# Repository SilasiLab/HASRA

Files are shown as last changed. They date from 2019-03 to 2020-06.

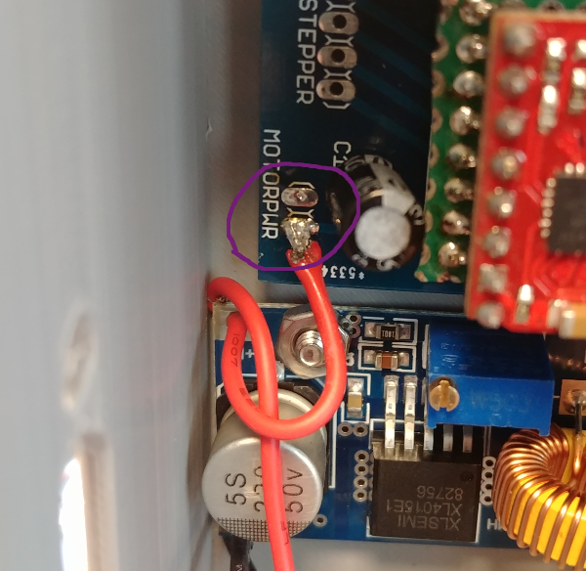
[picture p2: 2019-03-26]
resources/Images/STEP12.png

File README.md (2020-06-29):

# **Overview**:

This system allows the user to host up to 5 mice in their home environment and automatically administer the single pellet reaching test to those animals. The system can run unsupervised and continuously for weeks at a time, allowing all 5 mice to perform an unlimited number of single pellet trials at their leisure. 

The design allows a single mouse at a time to enter the reaching tube. Upon entry, the animal’s RFID tag will be read, and if authenticated, a session will start for that animal. A session is defined as everything that happens from the time an animal enters the reaching tube to when they leave the tube. At the start of a session, the animal’s profile will be read and the task difficulty as well as the left and right preference will be automatically adjusted by moving the pellet presentation arm to the appropriate distance both away from the reaching tube and from right to left. Pellets will continue to be presented periodically until the mouse leaves the tube, at which point the session will end. Video and other data is recorded for the duration of each session. At session end, all the data for the session is saved in an organized way. We also have an auxiliary function for counting the successful rate of displaying a pellet using MobileNetV2 based on tensorflow and keras.

For further analyse, you can check the repository posted here:
https://github.com/SilasiLab/HomecageSinglePellet_Manual

# **Dependencies:**
* Ubuntu v16.04 LTS: Kernel version 4.4.19-35 or later
* Or Windows 10 is recommended, since the backend camera driver performs better that the one on linux in our experiment.
* Anaconda 3 environment, for the dependancies without a version number, it means there is no specific requirement on it. 
	* Python==3.6.10
	* pySerial==3.4	
	* numpy==1.18.1
	* OpenCV=4.1.2 (A whl file is provided under requirment folder.)
	* tkinter=8.6.8
	* matplotlib=3.1.3
	* Pillow
	* tqdm
	* tensorflow=1.10.0
	* keras=2.2.4
	* psutil
	* multiprocessing
	* subprocess
	
* Arduino IDE v1.8.5

# **Software Installation:**
1. Windows 10 is strongly recommended for a better support of camera driver. Ubuntu 16.04 LTS is alternative.
2. Install Anaconda. (https://www.anaconda.com/distribution/)
3. Install Arduino IDE v1.8.5. (https://www.arduino.cc/en/Main/Software)
	
4. Create and configure a virtual environment for installing the HomeCageSinglePellet code.
	- `conda create -n <yourenvname> python=3.6.10 anaconda`
	- `conda activate <yourenvname>`
	- `conda install -c anaconda numpy==1.18.1`
	- `conda install -c anaconda pyserial==3.4`
	- `conda install -c anaconda tk==8.6.8`
	- `conda install -c conda-forge matplotlib`
	- `conda install tqdm`
	- `conda install Pillow`
	- `conda install tensorflow==1.10.0`
	- `conda install keras==2.2.4`
	- `pip install psutil`

5. `git clone https://github.com/SilasiLab/HomeCageSinglePellet_server.git`
6. `pip install /path/to/HASRA/dependencies/opencv_python-4.1.2+contrib-cp36-cp36m-win_amd64.whl`
7. Add ID of cage to the name of folder as postfix. (Rname the folder of the downloaded reporsitory as HASRA_[id]).
8. Create folders and profiles of the animals by running the  `genProfiles.py `
	- `conda activate [name of your environment]`
	- `cd /path/to/HASRA/src/client`
	- `python genProfiles.py`
# **Assembly:**

The detailed assembly manual can be found here:
https://github.com/SilasiLab/HomeCageSinglePellet_server/blob/master/Homecage%20assembly%20manual.pdf

# **Usage**:
### **Running the Device**
1. Enter the virtual environment that the system was installed in by typing `conda activate <my_env>` into a terminal.

2. Optional: Use `cd` to navigate to` HomeCageSinglePellet_server/src/client/` and then run `python -B genProfiles.py`. The text prompts will walk you through entering your new animals into the system. Since the folder and the file are already inclued in this repo, this step is optional.

3. Open HomeCageSinglePellet_server/config/config.txt and set the system configuration you want.

4. Find the COM port ids for Arduino and RFID reader, using `mode` command in terminal.
(In linux: Arduino needs to be USB0 , and RFID reader needs to be USB1. You can see connected USB devices with terminal command:
ls /dev/tty* and You need to replace the COMs in main.py -> `sys_init()` function manually.) 
  
5. Open a termanal and run following command:
* `cd \your\path\to\HomeCageSinglePellet_server\src\client\`
* `conda activate YourEnvironment` replace YourEnvironment by the name of your environment.
* `python main.py COM-arduino COM-RFID` replace COM-arduino and COM-RFID by the COM ids of Arduino and RFID respectively.

6. Optional: If you have a google file stream mounted on this computer, you can choose to upload all the viedos and log files to google drive. You need firstly find out the local path to this google drive folder, in this case it is: `G:\Shared drives\SilasiLabGdrive`.
Since there could be mutiple cage running on the same computer and they can also be stored in the same google cloud folder. You can add a suffix to the project foler name by changing the root folder name from `HomeCageSinglePellet_server` to `HomeCageSinglePellet_server_id`(replace the id by your id) 
In the same folder, open another terminal and activate the virtual environment again, then run `python googleDriveManager.py \path\to\your\cloud\drive\folder`.
The videos and the log files will be stored in `your cloud drive\homecage_id_sync`.

7. You need to put in the RFID tag numbers manually into the profiles. Take mouse 1 as an instance, you need to replace the first line in `HomeCageSinglePellet_server\AnimalProfiles\MOUSE1\MOUSE1_save.txt`. If you do not know your tag number, don't worry. You can scan it on the RFID reader, it will be printed in the Terminal as `[tag number] not recognized`.

8. To test that everything is running correctly, block the IR beam breaker with something
	and scan one of the system’s test tags. If a session starts properly, it’s working. You will also be able to find out hom many pellets have been succefully displayed out of current displays we have as it is shown in the terminal too. 

9. To shut the system down cleanly; 

	- Ensure no sessions are currently running. 
	- Press the quit button on the GUI.
	- Ctrl+c out of the program running in the terminal.

# **Troubleshooting**:

* Is everything plugged in?
* Make sure you are in the correct virtual environment.
* Make sure the HomeCageSinglePellet/config/config.txt file contains the correct configuration. (If the file gets deleted it will be replaced by a default version at system start)
* Make sure there are 1 to 5 profiles in the HomeCageSinglePellet/AnimalProfiles/ directory. Ensure these profiles contain all the appropriate files and that the save.txt file for each animal contains the correct information.

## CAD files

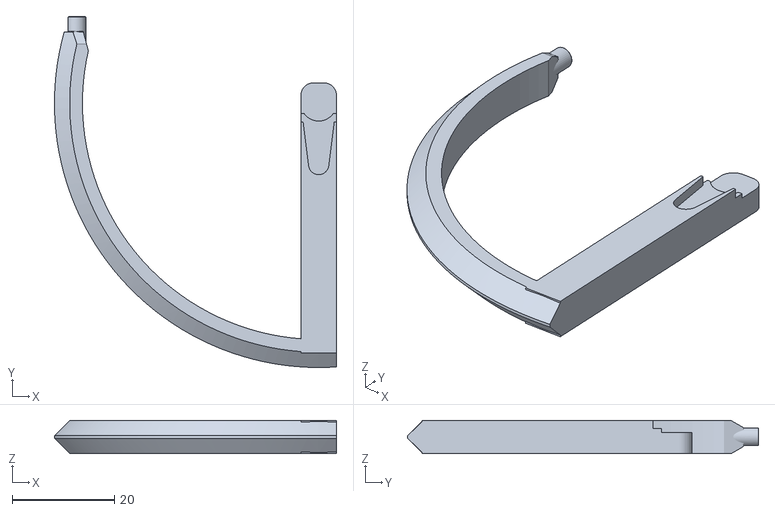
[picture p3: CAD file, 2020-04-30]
CAD/Arm.STL
55.3 x 68.8 x 6.50

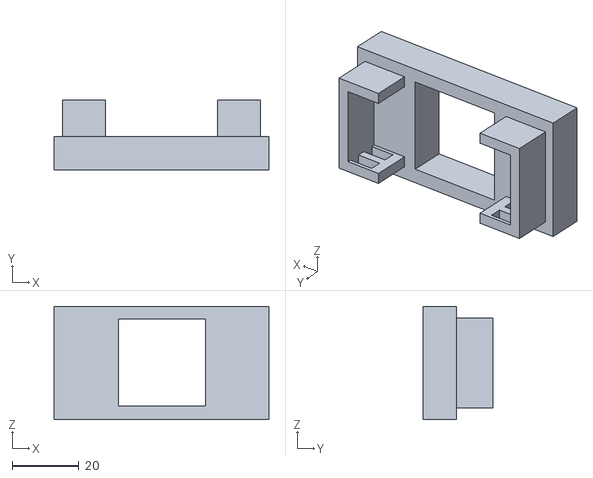
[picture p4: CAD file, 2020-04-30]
CAD/Beam_Breaker_Mount.STL
64.5 x 21.1 x 34.0

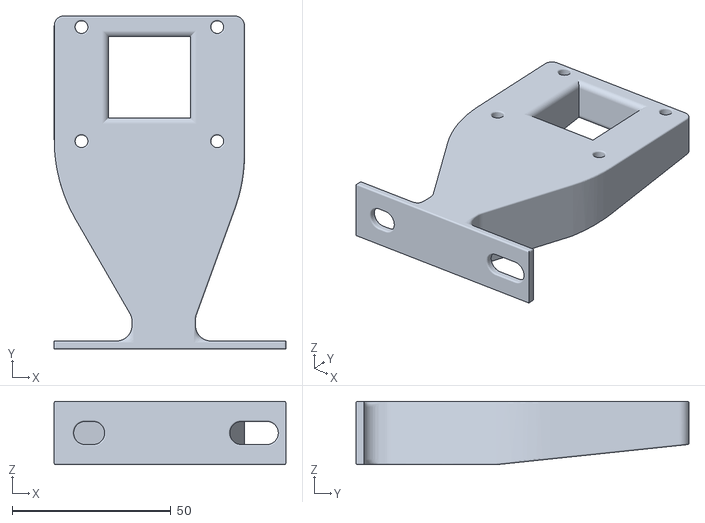
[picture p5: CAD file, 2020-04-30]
CAD/Standard.STL
73.0 x 105.0 x 20.0

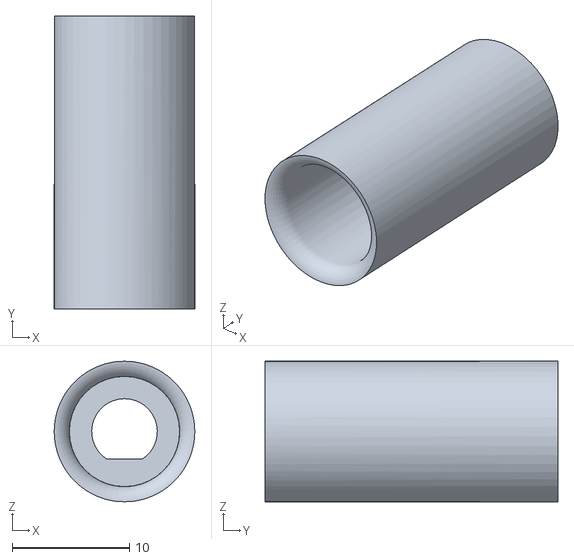
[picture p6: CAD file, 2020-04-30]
CAD/Motor_coupler.STL
12.0 x 25.0 x 12.0

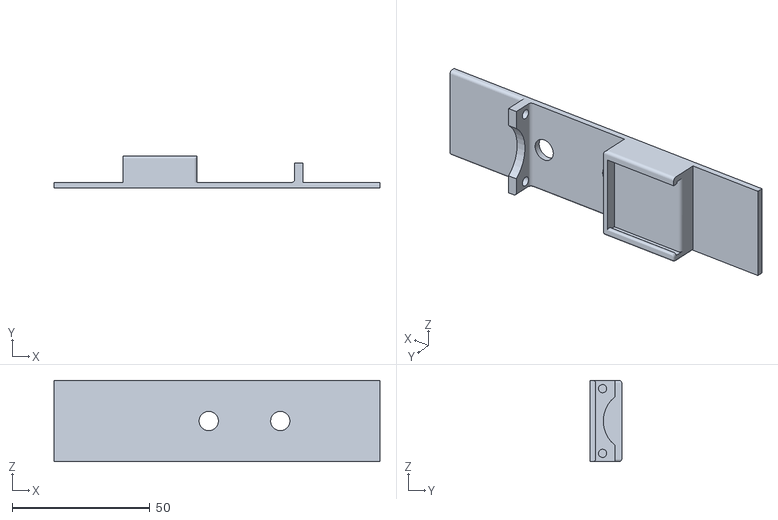
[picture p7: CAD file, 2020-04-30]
CAD/Moving_Stage_Bottom.STL
118.5 x 11.5 x 29.5

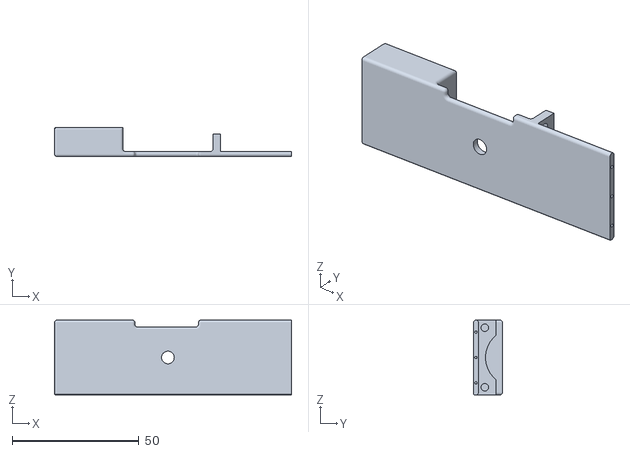
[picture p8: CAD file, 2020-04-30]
CAD/Moving_Stage_Top.STL
93.5 x 11.5 x 29.5

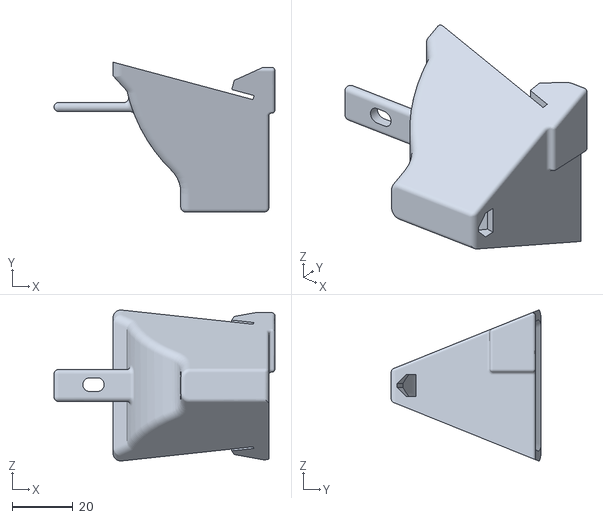
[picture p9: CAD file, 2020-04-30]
CAD/Hopper.STL
72.7 x 49.3 x 49.7

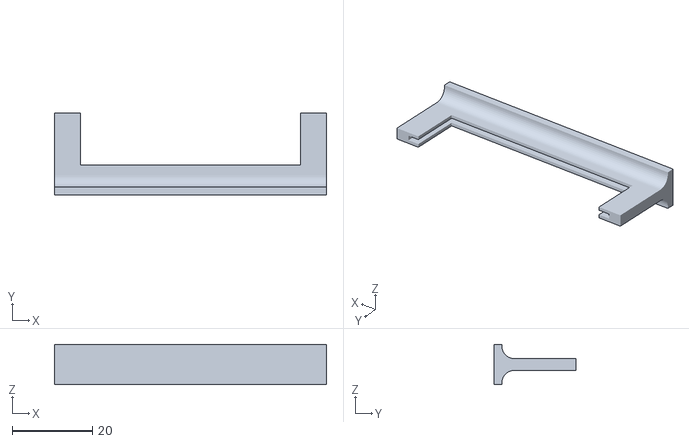
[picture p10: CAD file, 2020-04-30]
CAD/Light_Holder.STL
68.0 x 20.5 x 10.0

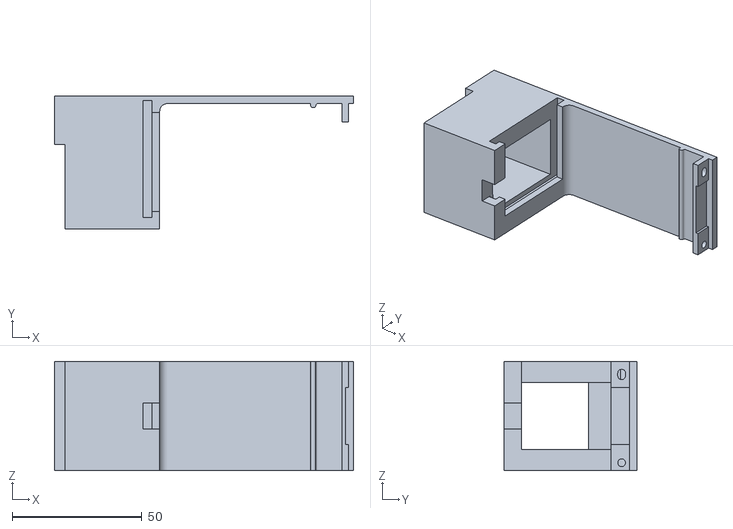
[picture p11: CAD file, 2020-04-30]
CAD/Tubeholder_3cm.STL
115.1 x 51.4 x 42.0

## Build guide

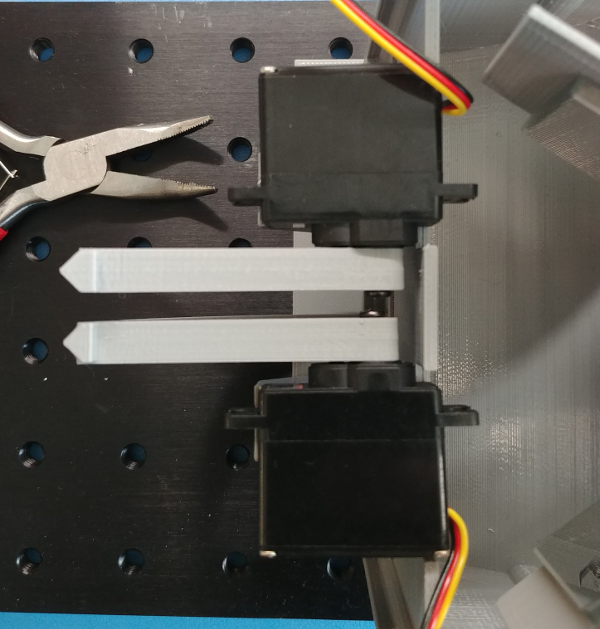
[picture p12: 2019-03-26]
resources/Images/STEP31.png

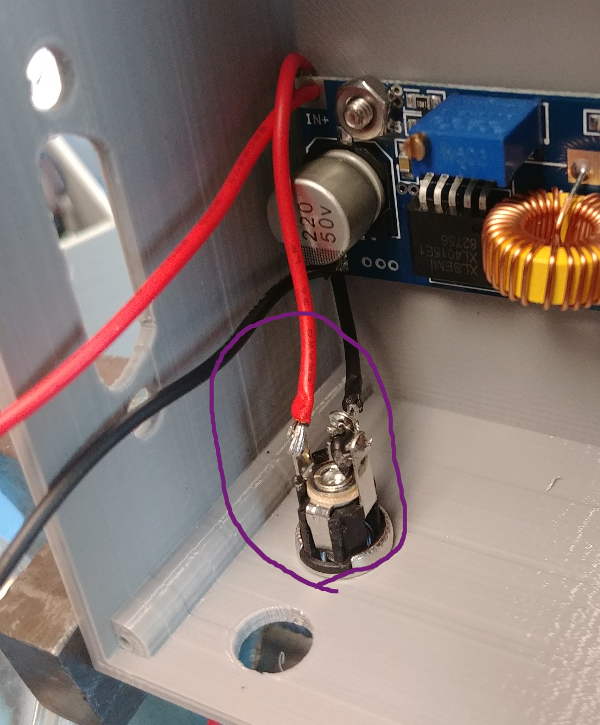
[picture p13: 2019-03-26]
resources/Images/STEP10.png

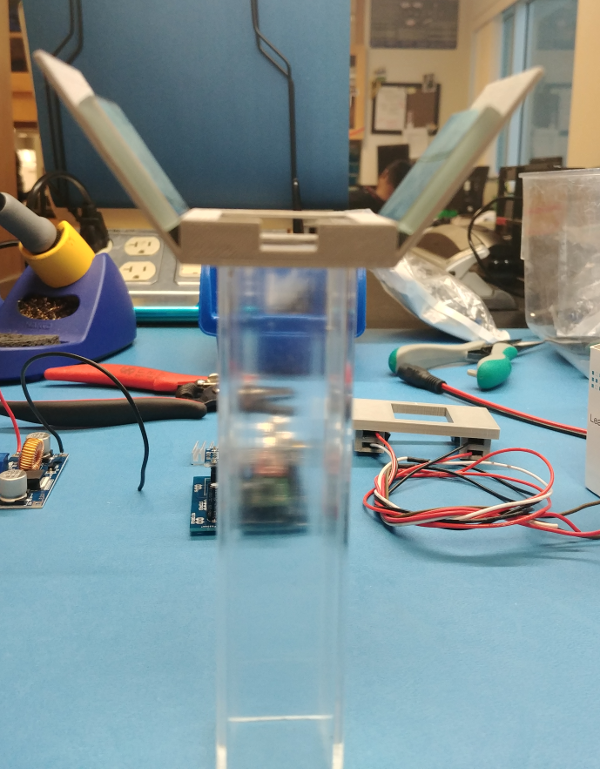
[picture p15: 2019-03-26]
resources/Images/STEP22.png

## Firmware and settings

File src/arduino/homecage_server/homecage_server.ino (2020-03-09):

/*
    This program is a server for controlling the hardware peripherals attached to the HomeCage system.
    It waits for commands over a serial port (python client in our case) and performs the desired action upon receiving the command.
    There is no proper message passing system and it simply uses various magic byte values as messages.
    Note: These bytes can cause different outcomes depending on the state the program is in at the time
    of receiving. The lack of real message passing system means the program is rather fragile. I recommend
    not modifying this program too much. Utility may instead be found by recycling specific functions.
    (For controlling servos, steppers, IR breakers, etc....attached to the Arduino).


    This program enters a listening mode on boot and waits for a signal over serial to tell it to start a session.
    Once this signal is received, the program expects to receive a byte value representing how far the stepper should
    rotate from the origin (The origin is defined on start-up by retracting the stepper motor until the limit switch
    is pressed). After the stepper motor is positioned, the program expects to receive repeating requests for
    pellet presentations (with either arm). The program continues in this state until the IR breaker is connected.
    At this point the server sends a session termination message to the client and tears the session down, re-entering
    it's default listening mode.


    Author: Julian Pitney, Junzheng Wu
    Email: JulianPitney@gmail.com, jwu220@uottawa.ca
    Organization: University of Ottawa (Silasi Lab)

*/

#include <Servo.h>

// Config
const int servo1Pin = 8;
Servo servo1;

bool servo1_up_flag = false;
const int SERVO_SETTLE_DELAY = 300;
// Higher numbers make the arm go higher
int SERVO1_UP_POS = 98;
// Low numbers makehe arm go lower
int SERVO1_DOWN_POS = 160;

int SERVO_PULSE_DELAY = 16;
int servo1Pos = SERVO1_DOWN_POS;


typedef enum {x, y} whichStepper;
const int ledPin = 13;
const int switchPin1 = 9;
const int switchPin2 = 10;
const int IRBreakerPin = A2;
const int vibrationPin = A1;
const int digitalSwitchPin = A3;

const int step1_left = 2;
const int step1_right = 3;
const int step1_sleep = 4;

const int step2_left = 5;
const int step2_right = 6;
const int step2_sleep = 7;



volatile byte switchState1 = digitalRead(switchPin1);
volatile byte switchState2 = digitalRead(switchPin2);
volatile byte IRState = digitalRead(IRBreakerPin);

int stepperDistFromOrigin = -1;
double stepsToMmRatio = 420;

void handleSwitchChange1() {
  switchState1 = digitalRead(switchPin1);
}
void handleSwitchChange2() {
  switchState2 = digitalRead(switchPin2);
}

void handleIRChange() {
  IRState = digitalRead(IRBreakerPin);  
  digitalWrite(ledPin, IRState);
}

int my_delay(int delay_time){
    for(int i = 0; i < delay_time; i += 1)
      {
          delay(1);
          if (digitalRead(IRBreakerPin))
            return 0;
      }
     return 1;
  }

int zeroServos() {

  servo1.attach(servo1Pin);

  for (int i = servo1Pos; i <= SERVO1_DOWN_POS; i += 1) {
      servo1.write(i);
      delay(SERVO_PULSE_DELAY);
    }   
  delay(SERVO_SETTLE_DELAY);
  servo1Pos = SERVO1_DOWN_POS;
  
  servo1.detach();
  return 1;

}

int lowerServo1(){
 
  servo1.attach(servo1Pin);
   
  for (int i = servo1Pos; i <= SERVO1_DOWN_POS; i += 1) {
      servo1.write(i);
      delay(SERVO_PULSE_DELAY);
    }   
  delay(SERVO_SETTLE_DELAY);
  servo1Pos = SERVO1_DOWN_POS;
  
  servo1.detach();
  return 1;
}

int displayPellet() {
    
  servo1.attach(servo1Pin);

  // Lower arm to grab pellet.
  for (int i = servo1Pos; i <= SERVO1_DOWN_POS; i += 1) {
    if (digitalRead(IRBreakerPin)){servo1.detach();return 0;}
    servo1.write(i);
    //delay(SERVO_PULSE_DELAY);
    if (my_delay(SERVO_PULSE_DELAY) == 0){servo1.detach();return 0;}
  }   
  // Raise arm to display pellet
  if (my_delay(SERVO_PULSE_DELAY) == 0){servo1.detach();return 0;}
  
  for (int i = SERVO1_DOWN_POS; i >= SERVO1_UP_POS; i -= 1) {
    if (digitalRead(IRBreakerPin)){servo1.detach();return 0;}
    servo1.write(i);
    //delay(SERVO_PULSE_DELAY);
    if (my_delay(SERVO_PULSE_DELAY) == 0){servo1.detach();return 0;}
  }
  
  if (my_delay(SERVO_SETTLE_DELAY) == 0){servo1.detach();return 0;}

  servo1Pos = SERVO1_UP_POS;
  servo1_up_flag = true;
  servo1.detach();
  return 1;
}

int moveStepper_both(int targetPos1, int targetPos2) {
  digitalWrite(step1_sleep, HIGH);
  digitalWrite(step2_sleep, HIGH);
  //delay(100);
  if (my_delay(100) == 0){
    digitalWrite(step1_sleep, LOW);
  digitalWrite(step2_sleep, LOW);
  return 0;}
  
  int step1 = 0;
  int step2 = 0;
  
  if(targetPos1 > 0){step1 = -1; digitalWrite(step1_left, HIGH);}
  else{step1 = 1; digitalWrite(step1_left, LOW);}
  if(targetPos2 > 0){step2 = -1; digitalWrite(step2_left, LOW);}
  else{step2 = 1; digitalWrite(step2_left, HIGH);}
  
  int count1 = targetPos1 * stepsToMmRatio;
  int count2 = targetPos2 * stepsToMmRatio;
  
  while((count1 != 0) || (count2 != 0))
  {
    if (digitalRead(IRBreakerPin)){return 0;}
    if(count1 != 0)
    {
      count1 += step1;
      digitalWrite(step1_right, HIGH);
    }
    if(count2 != 0)
    {
      count2 += step2;
      digitalWrite(step2_right, HIGH);
    }
    delayMicroseconds(500);
    if(count1 != 0)
    {
      digitalWrite(step1_right, LOW);
    }
    if(count2 != 0)
    {
      digitalWrite(step2_right, LOW);
    }
    delayMicroseconds(500);
      
  }
  digitalWrite(step1_sleep, LOW);
  digitalWrite(step2_sleep, LOW);
  return 1;
}



int zeroStepper_both(){

  int left = 0;
  int right = 0;
  
  digitalWrite(step1_sleep, HIGH);
  digitalWrite(step2_sleep, HIGH);
  delay(100);
  digitalWrite(step1_left, LOW);
  digitalWrite(step2_left, HIGH);
  delay(100);
  while((!digitalRead(switchPin1)) || (!digitalRead(switchPin2))){
    digitalWrite(vibrationPin, HIGH);
    if (!digitalRead(switchPin1)){digitalWrite(step1_right, LOW);}
    if (!digitalRead(switchPin2)){digitalWrite(step2_right, LOW);}
    delayMicroseconds(500);
    if (!digitalRead(switchPin1)){digitalWrite(step1_right, HIGH);}
    if (!digitalRead(switchPin2)){digitalWrite(step2_right, HIGH);}
    delayMicroseconds(500);
  }
  digitalWrite(vibrationPin, LOW);
  digitalWrite(step1_sleep, LOW);
  digitalWrite(step2_sleep, LOW);
  return 1;
}


void setup() {

  // Open serial connection
  // Note: This takes a bit to connect so while(!Serial) keeps it waiting
  // until the connection is ready.
  Serial.begin(9600);
  while (!Serial) {
    //if (my_delay(100) == 0){return;}
    delay(100);
  }
  pinMode(digitalSwitchPin, OUTPUT);
  digitalWrite(digitalSwitchPin, LOW);
  
  pinMode(vibrationPin, OUTPUT);
  digitalWrite(vibrationPin, LOW);
  zeroServos();
  
  pinMode(step1_sleep, OUTPUT);
  pinMode(step2_sleep, OUTPUT);
  
  pinMode(switchPin1, INPUT_PULLUP);
  switchState1 = digitalRead(switchPin1);
  attachInterrupt(digitalPinToInterrupt(switchPin1), handleSwitchChange1, CHANGE);

  pinMode(switchPin2, INPUT_PULLUP);
  switchState2 = digitalRead(switchPin2);
  attachInterrupt(digitalPinToInterrupt(switchPin2), handleSwitchChange2, CHANGE);

  pinMode(IRBreakerPin, INPUT_PULLUP);
  IRState = digitalRead(IRBreakerPin);
  attachInterrupt(digitalPinToInterrupt(IRBreakerPin), handleIRChange, HIGH);
  
  // Set LED control pin
  pinMode(ledPin, OUTPUT);
  digitalWrite(ledPin, HIGH);
  Serial.write("READY\n");
  return;
}

bool listenForStartCommand() {
  char authByte;
  while(true) {
    if(Serial.available() > 0) {
      authByte = Serial.read();
    }
    else{return false;}
    if(authByte == 'A') {
      return true;
    }
    else if (authByte == 'Y' ) {
      digitalWrite(ledPin, HIGH);
      return false;
    }

  }
}

int startSession() {
  bool startedflag = false;
  while(!digitalRead(IRBreakerPin)) {
    startedflag = true;
    char cmd;
    char stepperDist1;
    char stepperDist2;
    int stepperDistInt1;
    int stepperDistInt2;
    if(Serial.available() > 0) {
      cmd = Serial.read();
      
      switch(cmd){
        
        case ('1'):
          if(displayPellet() == 0){return 0;}
          break;
          
        case ('2'):
          if(displayPellet() == 0){return 0;}
          break;
          
        case ('3'):

          // Give client a second to respond
          //delay(200);
          if (my_delay(200) == 0){return 0;}
             
          stepperDist1 = Serial.read();
            
          //delay(200);
          if (my_delay(200) == 0){return 0;} 
          
          stepperDist2 = Serial.read();

          if (isDigit(stepperDist1)){stepperDistInt1 = stepperDist1 - '0';}
          else{stepperDistInt1 = 10 + stepperDist1 - 'a';}
          if (isDigit(stepperDist2)){stepperDistInt2 = stepperDist2 - '0';}
          else{stepperDistInt2 = 10 + stepperDist2 - 'a';}
          if (moveStepper_both(stepperDistInt1, stepperDistInt2) == 0){return 0;} 
          break;
        case ('4'):
          if(displayPellet() == 0){return 0;}
          break;
        default:
          break;
      }
    }
    
  }
  if(servo1_up_flag)
  {
    lowerServo1();
    servo1_up_flag = false;
  }
  
  return 0;
  
}

void test_switch(){
  while(!digitalRead(switchPin2)){
    digitalWrite(ledPin, HIGH);
  }
  digitalWrite(ledPin, LOW);
  delay(500);
}

void test_beambreaker(){
  while(!digitalRead(IRBreakerPin)){
    digitalWrite(ledPin, HIGH);
    }
  digitalWrite(ledPin, LOW);
  delay(500);
}

void test_servo(){
  displayPellet();
  delay(1000);
  zeroServos();
}

void test_stepper(){
  zeroStepper_both();
  moveStepper_both(7, 11);
}

void loop(){
  boolean DEBUG = false;
  if(DEBUG){
    test_stepper();
    displayPellet();

    digitalWrite(digitalSwitchPin, HIGH);
  }
  else{
    if(listenForStartCommand()){
    digitalWrite(digitalSwitchPin, HIGH);
    digitalWrite(ledPin, LOW);
    startSession();
    Serial.write("TERM\n");
    digitalWrite(digitalSwitchPin, LOW);
    zeroServos();
    zeroStepper_both();
    
    }
  }
  digitalWrite(ledPin, HIGH);  
}

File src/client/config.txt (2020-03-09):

COM27
USB VID:PID=1A86:7523 SER=5 LOCATION=1-2
1-2
******************* 
COM16
USB VID:PID=1A86:7523 SER=5 LOCATION=1-4
1-4
******************* 
COM1
USB VID:PID=0000:0000
None
******************* 
COM18
USB VID:PID=0403:6001 SER=A6024DMNA
None
******************* 
COM23
USB VID:PID=0403:6001 SER=A9084Y1CA
None
******************* 
COM28
USB VID:PID=1A86:7523 SER=7 LOCATION=1-6.1.2
1-6.1.2
******************* 
COM19
USB VID:PID=0403:6001 SER=AH05K4CXA
None
******************* 
COM3
USB VID:PID=0000:0000
None
******************* 

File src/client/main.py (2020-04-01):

"""
    Author: Julian Pitney, Junzheng Wu
    Email: JulianPitney@gmail.com, jwu220@uottawa.ca
    Organization: University of Ottawa (Silasi Lab)
"""

import gui
import arduinoClient
import systemCheck
import time
import multiprocessing
import serial
from subprocess import PIPE, Popen
import os
import datetime
from driver_for_a_better_camera import *
from googleDriveManager import is_locked
import numpy as np
from detector import Detector
import sys

D = Detector("model/model.h5")
systemCheck.check_directory_structure()
# Load all configuration information for running the system.
# Note: Configuration information for data analysis does not come from here.

dirpath = os.getcwd()
base_dir = dirpath.split('src'+os.sep+'client')[0]
PROFILE_SAVE_DIRECTORY = os.path.join(base_dir, 'AnimalProfiles')


# This function generates a list of AnimalProfiles found inside <profile_save_directory>.
# It then reads the save.txt file for each profile found, and uses the information
# in that file to reconstruct the AnimalProfile object. It returns all the
# reconstructed profiles as a list of AnimalProfiles.
# Note: This function works by assuming the directory structure of each AnimalProfile
# is consistent and the required save.txt files are present, i.e:
#
# <profile_save_directory>
#   -
#   - ProfileName
#       -
#       - Logs
#       - Videos
#       - save.txt
mouse1TrialLimit = None
mouse2TrialLimit = None
mouse3TrialLimit = None
mouse4TrialLimit = None
mouse5TrialLimit = None

mouse1TrialsToday = 0
mouse2TrialsToday = 0
mouse3TrialsToday = 0
mouse4TrialsToday = 0
mouse5TrialsToday = 0

def loadAnimalProfileTrialLimits():

    global mouse1TrialLimit, mouse2TrialLimit, mouse3TrialLimit, mouse4TrialLimit, mouse5TrialLimit

    with open(".." + os.sep + ".." + os.sep + "config" + os.sep + "trialLimitConfig.txt") as f:
        # print(f.readline().rstrip())
        mouse1TrialLimit = int(f.readline().rstrip())
        mouse2TrialLimit = int(f.readline().rstrip())
        mouse3TrialLimit = int(f.readline().rstrip())
        mouse4TrialLimit = int(f.readline().rstrip())
        mouse5TrialLimit = int(f.readline().rstrip())

def resetAnimalProfileTrialsToday():

    global mouse1TrialsToday, mouse2TrialsToday, mouse3TrialsToday, mouse4TrialsToday, mouse5TrialsToday
    currentDT = datetime.datetime.now()

    if(currentDT.hour == "07"):
        print("Resetting animal trial limits for the day!")
        mouse1TrialsToday = 0
        mouse2TrialsToday = 0
        mouse3TrialsToday = 0
        mouse4TrialsToday = 0
        mouse5TrialsToday = 0


def loadAnimalProfiles(profile_save_directory):
    # Get list of profile folders
    profile_names = os.listdir(profile_save_directory)
    profiles = []
    print(profile_names)
    for profile in profile_names:

        # Build save file path
        # load_file = profile_save_directory + profile + "/" + profile + "_save.txt"
        load_file = os.path.join(profile_save_directory , profile, profile + "_save.txt")
        profile_state = []
        # Open the save file
        try:
            load = open(load_file, 'r')
        except IOError:
            print("Could not open AnimalProfile save file!")

        # Read all lines from save file and strip them
        with load:
            profile_state = load.readlines()
        profile_state = [x.strip() for x in profile_state]

        # Create AnimalProfile object using loaded data and put it in profile list
        ID = profile_state[0]
        name = profile_state[1]
        mouseNumber = profile_state[2]
        cageNumber = profile_state[3]
        difficulty_dist_mm1 = profile_state[4]
        difficulty_dist_mm2 = profile_state[5]
        dominant_hand = profile_state[6]
        session_count = profile_state[7]
        animal_profile_directory = load_file.replace(name + "_save.txt", "")
        temp = AnimalProfile(ID, name, mouseNumber, cageNumber, difficulty_dist_mm1, difficulty_dist_mm2, dominant_hand, session_count,
                             animal_profile_directory, False)
        profiles.append(temp)

    return profiles


class AnimalProfile(object):

    #    A profile containing all information related to a particular animal. When a new animal is added to the system,
    #    an AnimalProfile should be created for that animal. This profile will be used by the rest
    #    of the system for any operation pertaining to the animal (data logging, identification, etc). When the application closes,
    #    saveProfile() should be called on each profile in the system. A global loadProfiles() function is used to load/reconstruct
    #    each profile at load time. Each AnimalProfile has the following properties:
    #
    #    Attributes:
    #        ID: A unique identification number for the animal. In our case this number will be the RFID of the RF tag implanted in the animal.
    #        name: The name of the animal
    #		 mouseNumber: The number of the animal in it's cage (0-5).
    #		 cageNumber: The cage number of the animal.
    #        difficulty_dist_mm: An integer representing the distance from the tube to the presented pellet in mm.
    #        dominant_hand: A string representing the dominant hand of the mouse.
    #        session_count: The number of Sessions the animal has participated in. In our system, this is the number of times the animal has
    #                        entered the experiment tube.
    #        animal_profile_directory: A path to the root folder where AnimalProfile's are stored.
    #        video_save_directory: A path to where the videos for this animal are stored. This path will be inside [./<animal_profile_directory>/<animal_name>/]
    #        log_save_directory: A path to where the logs for this animal are stored. This pathh will be inside [./<animal_profile_directory/<animal_name/]

    def __init__(self, ID, name, mouseNumber, cageNumber, difficulty_dist_mm1, difficulty_dist_mm2, dominant_hand, session_count,
                 profile_save_directory, is_new):

        self.ID = str(ID)
        self.name = str(name)
        self.mouseNumber = str(mouseNumber)
        self.cageNumber = str(cageNumber)
        self.difficulty_dist_mm1 = int(difficulty_dist_mm1)
        self.difficulty_dist_mm2 = int(difficulty_dist_mm2)
        self.dominant_hand = str(dominant_hand)
        self.session_count = int(session_count)

        if is_new:
            self.animal_profile_directory = profile_save_directory + name + os.sep
        else:
            self.animal_profile_directory = profile_save_directory

        self.video_save_directory = self.animal_profile_directory + "Videos" + os.sep
        self.log_save_directory = self.animal_profile_directory + "Logs" + os.sep

        if is_new:

            if not os.path.isdir(self.animal_profile_directory):
                os.makedirs(self.animal_profile_directory)

            if not os.path.isdir(self.video_save_directory):
                os.makedirs(self.video_save_directory)
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

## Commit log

2019-03-26 The isolated server part from HomeCageSinlePellt
    [MOUSE1_session_history.csv, MOUSE2_session_history.csv, MOUSE3_session_history.csv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]
2019-04-01 Add google drive manage function into main.py
    [MOUSE1_session_history.csv, MOUSE2_session_history.csv, MOUSE3_session_history.csv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]
2019-04-02 Fixed a bug
    [MOUSE1_session_history.csv, MOUSE2_session_history.csv, MOUSE3_session_history.csv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]
2019-04-02 fixed the bug in arduino.
    [TEST_RIGHT_session_history.csv]
2019-04-04 Add a function detetcting whether the video is under recording.
    [MOUSE1_session_history.csv, MOUSE2_session_history.csv, MOUSE3_session_history.csv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]
2019-04-04 Remove redundant print.
2019-04-08 add rclone self check function.
    [MOUSE1_session_history.csv, MOUSE2_session_history.csv, MOUSE3_session_history.csv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]
2019-04-29 Latest version for new cameras
2019-05-10 Latest version: 1.Fixed the old bug in Arduino code. 2.Been Modified to run on windows. 3.FPS has been set at a constant value.
    [MOUSE1_session_history.csv, MOUSE2_session_history.csv, MOUSE3_session_history.csv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]
2019-06-07 Add viberation motor driver in Arduino code.
2019-07-04 Latest version
    [config.txt, trialLimitConfig.txt]
2019-07-08 Add debuging function in arduino
    [TEST_RIGHT_session_history.csv]
2019-07-19 Add function in arduino coder for driving the vibration motor. Remove the initial trial from main.py code.
    [TEST_RIGHT_session_history.csv]
2019-08-08 add function for controling light.
    [TEST_RIGHT_session_history.csv]
2019-08-08 Modifications on GUI.
    [TEST_RIGHT_session_history.csv]
2019-08-15 new changes
    [TEST_RIGHT_session_history.csv]
2020-04-30 3d print
    [Arm.STL, Beam_Breaker_Mount.STL, Hopper.STL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]
2020-06-06 create CAD
    [Arm.STL, Beam_Breaker_Mount.STL, Hopper.STL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]
